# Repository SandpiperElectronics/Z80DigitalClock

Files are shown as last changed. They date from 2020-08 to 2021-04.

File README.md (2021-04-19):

# Z80 Digital Clock

## Description:
Built out of a Z80 microcomputer system of my own design, this clock can display Hours, Minutes, and Seconds and does so using an interupt from an Intel 82C53 Counter/Timer chip that is equally as vintage as the Z80.

## To Do: 
- [X] Clock Display
- [X] Clock Display PCB
- [X] Reset Circuit
- [X] Basic Functionality (ROM and CPU)
- [X] 8255 Peripheral Chip
- [X] 8253 Counter/Timer
- [ ] Write Display Sub Routine
- [ ] Clock Sub Routine
- [X] Buttons to Set time
- [ ] Sub routine for button input
- [ ] Z80 Clock PCB

## Images:

### Z80 Clock Schematic (New Version)
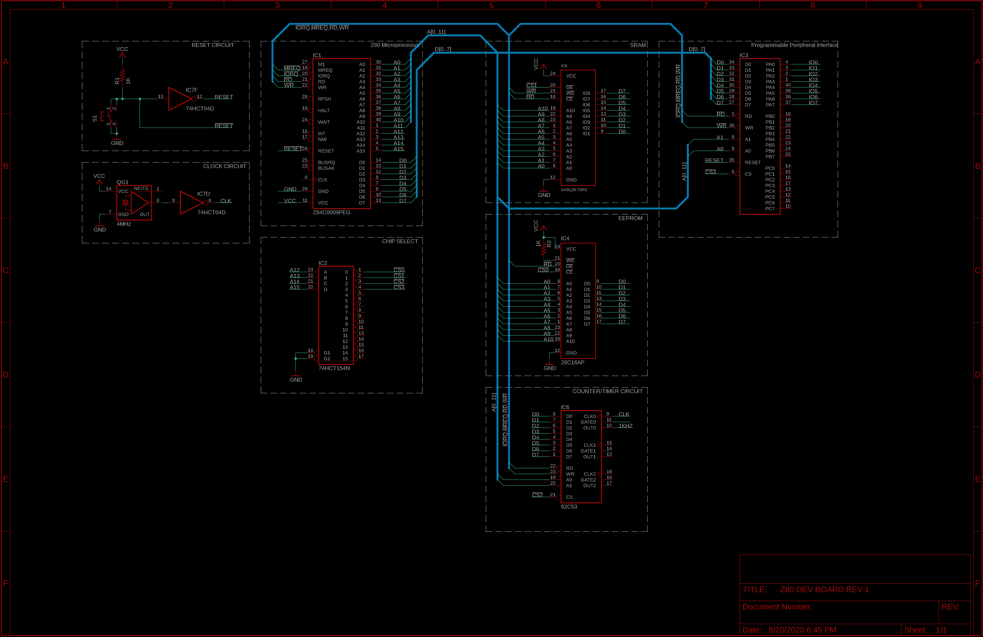
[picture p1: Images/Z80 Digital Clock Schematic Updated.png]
Image of Clock Schematic (NEW)


### Z80 Clock Schematic (Old Version)
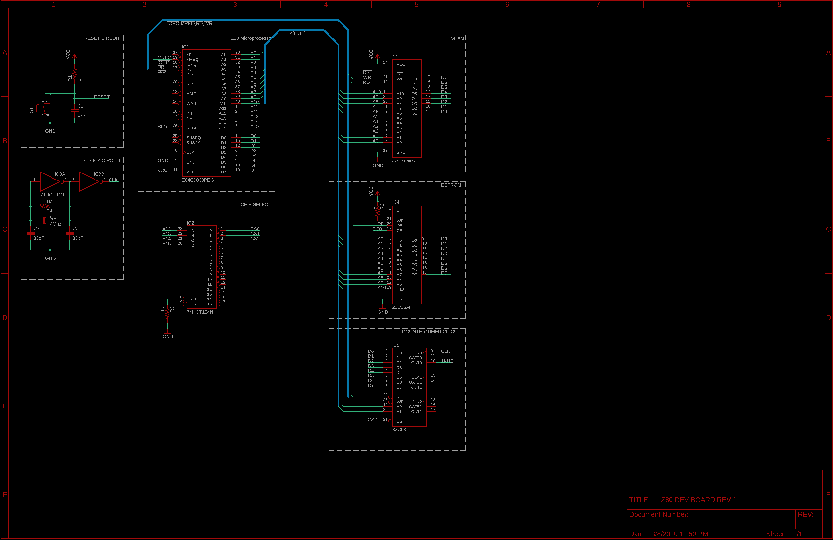
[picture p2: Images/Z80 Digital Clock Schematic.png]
Image of Clock Schematic (OLD)


### 7 Segment Peripheral Schematic
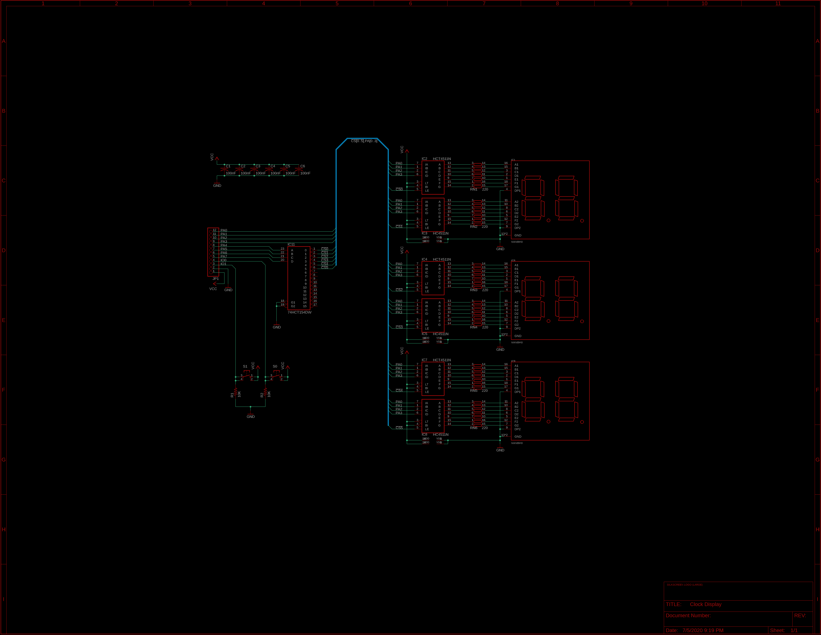
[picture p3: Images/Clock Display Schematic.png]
Image of 7 Segment Peripheral Schematic


### 7 Segment Peripheral Board Design
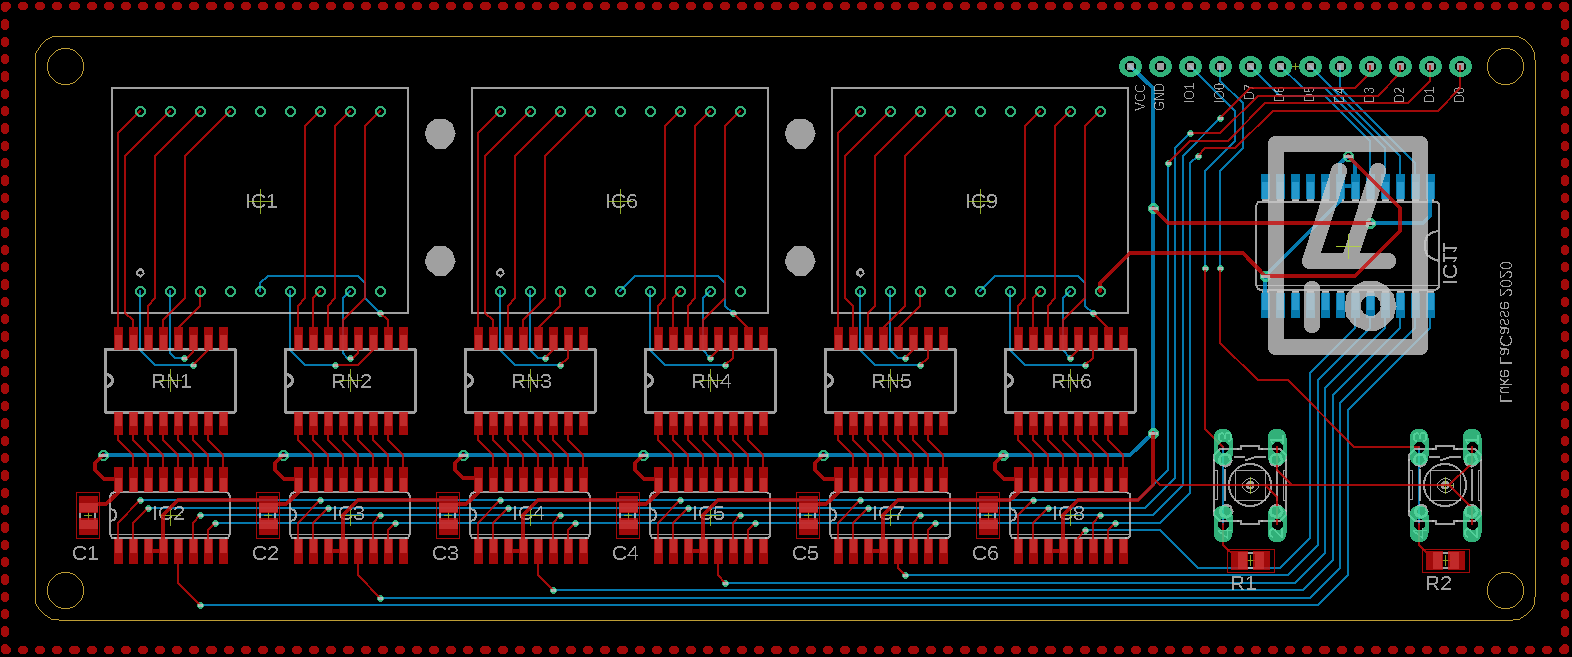
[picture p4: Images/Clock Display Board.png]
Image of 7 Sedment Peripheral PCB Design


### 7 Segment PCB and Z80 Clock
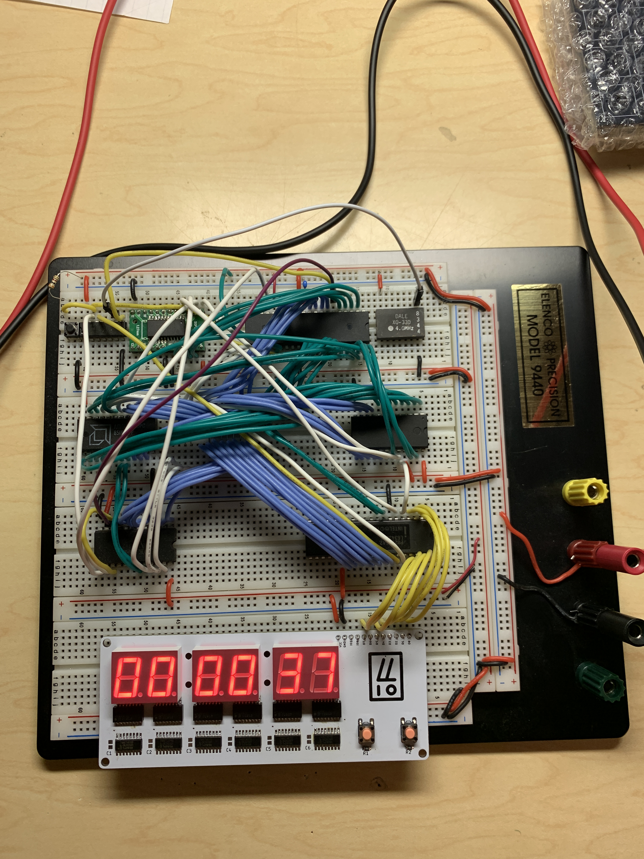
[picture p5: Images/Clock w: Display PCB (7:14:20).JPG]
Image of 7 Segment PCB and Z80 Clock


### 7 Segments in the Dark
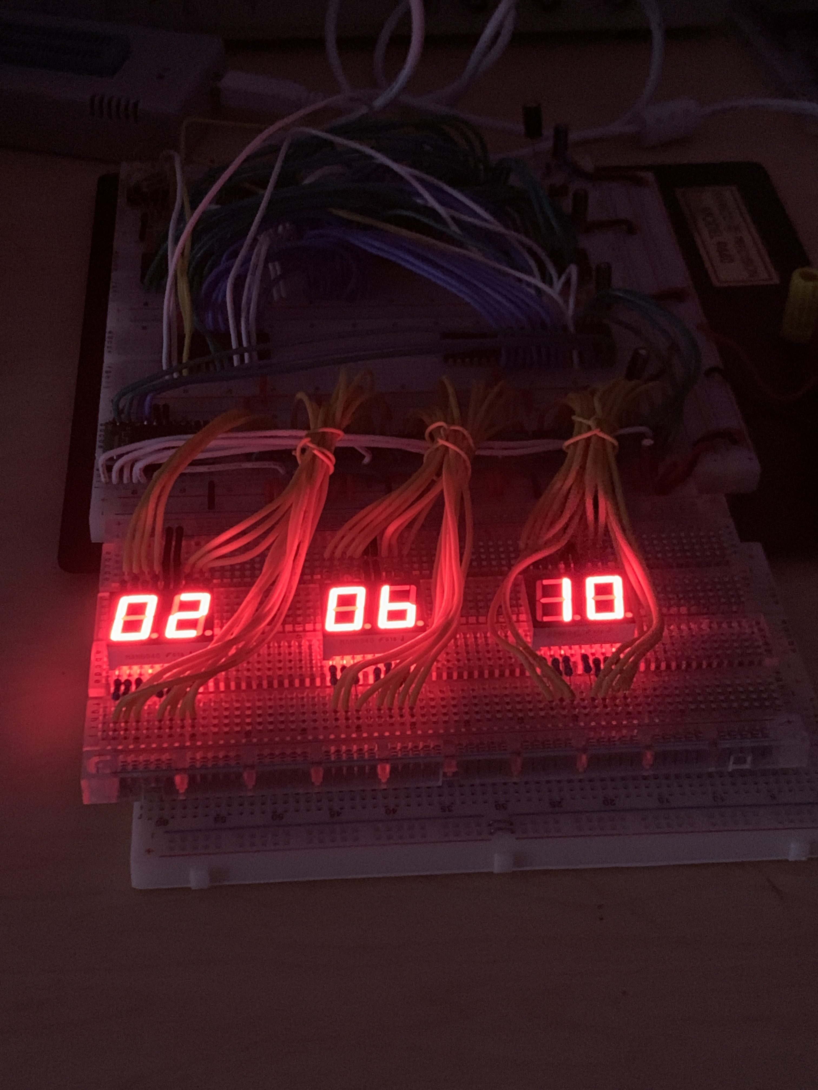
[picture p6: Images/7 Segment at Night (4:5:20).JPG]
Image of 7 Segments in the Dark


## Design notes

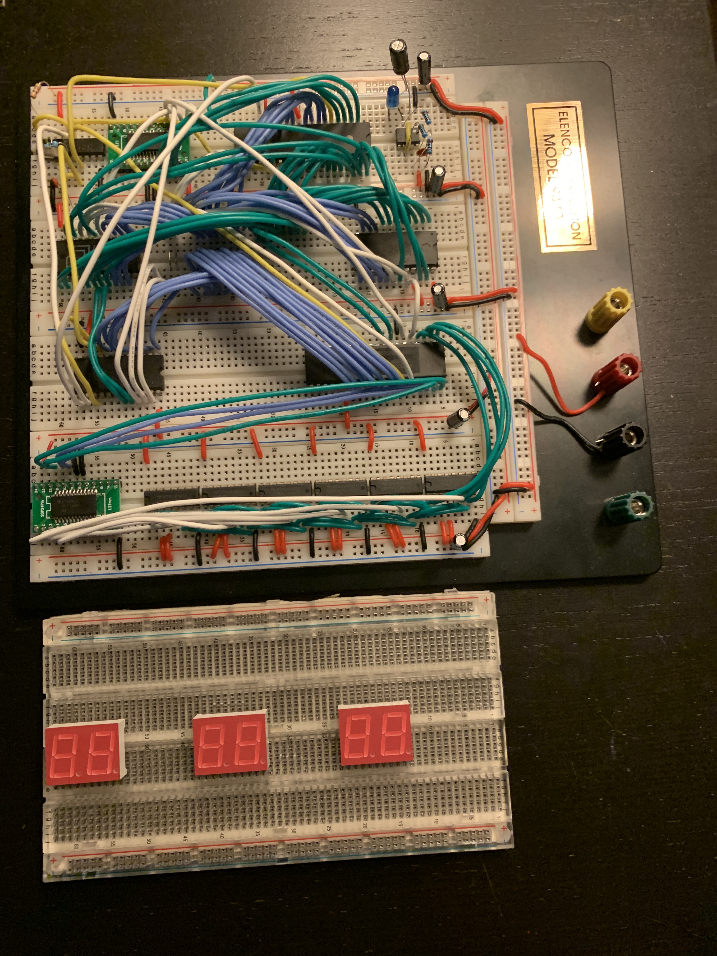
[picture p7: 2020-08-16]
Images/Before Connecting 7 Segment Displays (3:27:20) .JPG

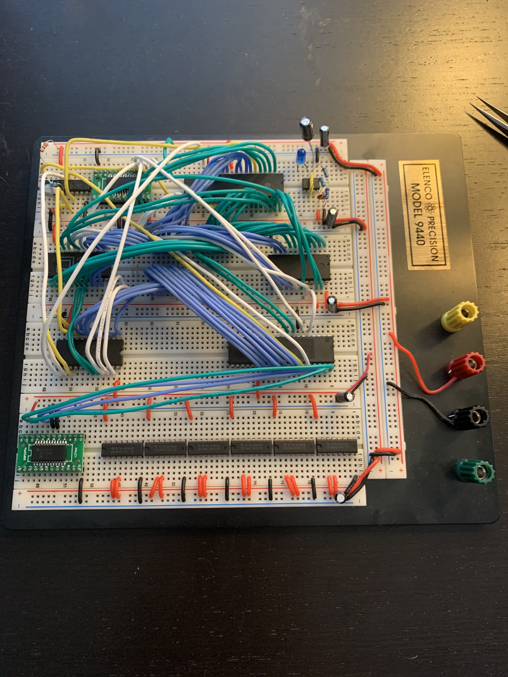
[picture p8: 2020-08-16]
Images/Adding 7 Segment Control (3:27:20).JPG

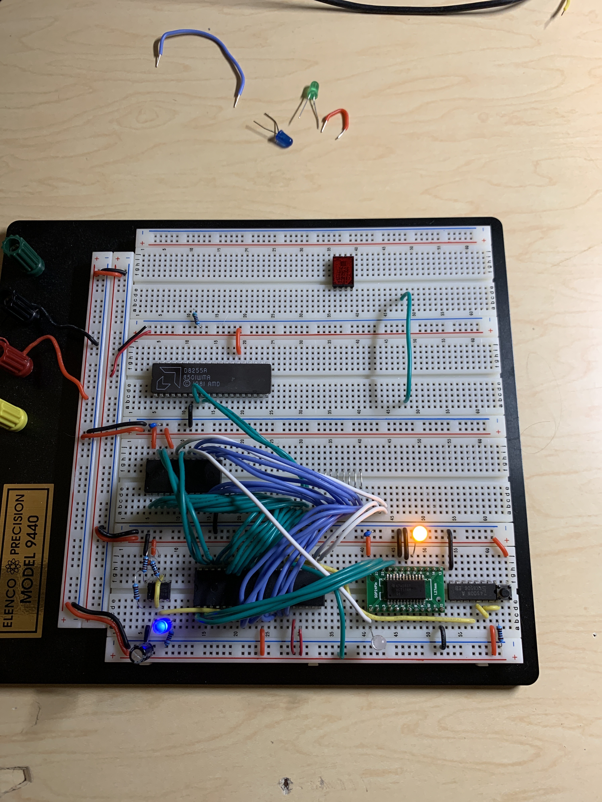
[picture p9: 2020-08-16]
Images/Early Stages (2:6:20).JPG

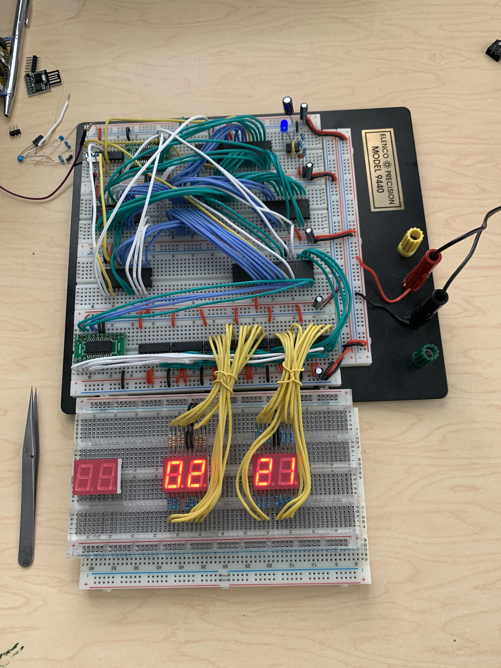
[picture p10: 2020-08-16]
Images/Two Displays Working (4:1:20).JPG

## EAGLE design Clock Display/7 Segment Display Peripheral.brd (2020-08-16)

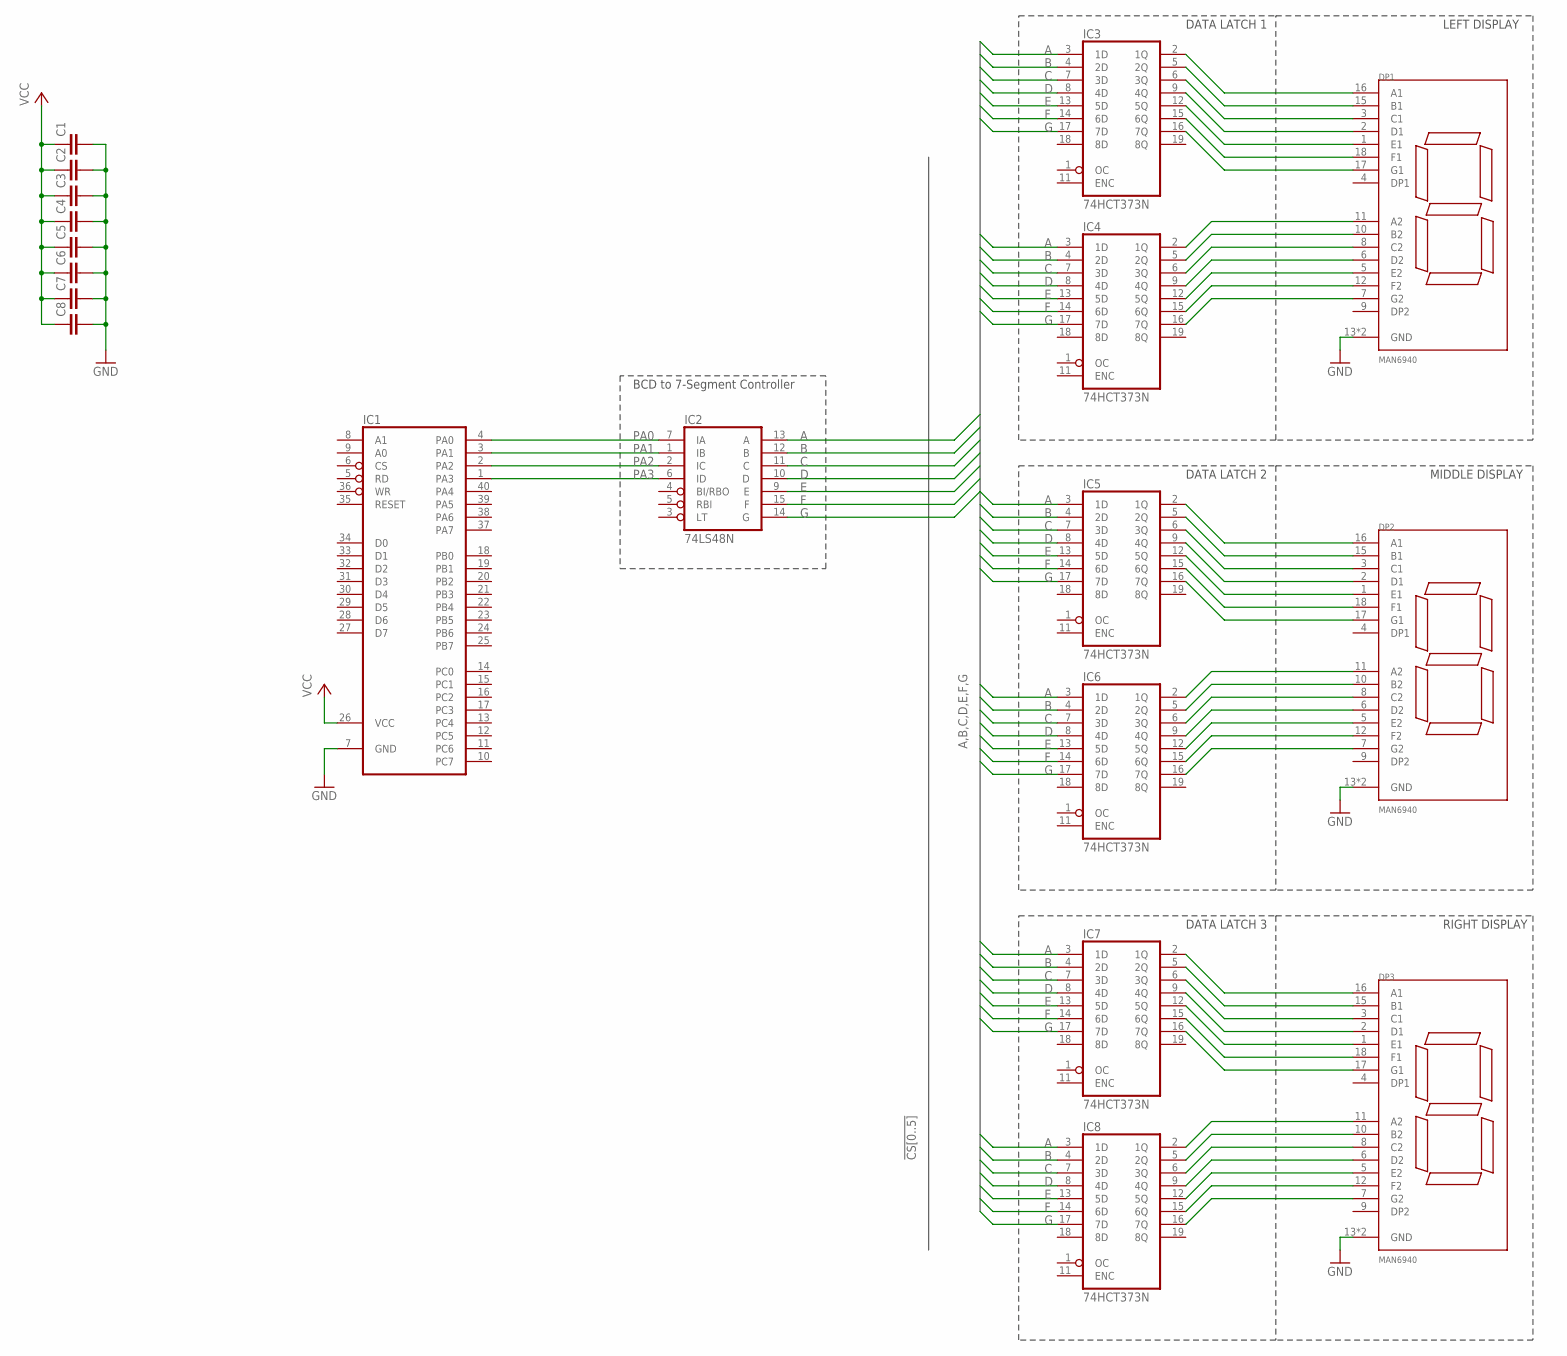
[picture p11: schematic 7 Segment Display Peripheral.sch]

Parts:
C1, C2, C3, C4, C5, C6, C7, C8: C-EU050-024X044; C050-024X044
DP1, DP2, DP3: MAN6940
IC1: 82C55A; DIL40
IC2: 74LS48N; DIL16
IC3, IC4, IC5, IC6, IC7, IC8: 74HCT373N; DIL20

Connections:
A: IC2.13 (A), IC3.3 (1D), IC4.3 (1D), IC5.3 (1D), IC6.3 (1D), IC7.3 (1D), IC8.3 (1D)
B: IC2.12 (B), IC3.4 (2D), IC4.4 (2D), IC5.4 (2D), IC6.4 (2D), IC7.4 (2D), IC8.4 (2D)
C: IC2.11 (C), IC3.7 (3D), IC4.7 (3D), IC5.7 (3D), IC6.7 (3D), IC7.7 (3D), IC8.7 (3D)
D: IC2.10 (D), IC3.8 (4D), IC4.8 (4D), IC5.8 (4D), IC6.8 (4D), IC7.8 (4D), IC8.8 (4D)
E: IC2.9 (E), IC3.13 (5D), IC4.13 (5D), IC5.13 (5D), IC6.13 (5D), IC7.13 (5D), IC8.13 (5D)
F: IC2.15 (F), IC3.14 (6D), IC4.14 (6D), IC5.14 (6D), IC6.14 (6D), IC7.14 (6D), IC8.14 (6D)
G: IC2.14 (G), IC3.17 (7D), IC4.17 (7D), IC5.17 (7D), IC6.17 (7D), IC7.17 (7D), IC8.17 (7D)
GND: C1.2, C2.2, C3.2, C4.2, C5.2, C6.2, C7.2, C8.2, DP1.13 (GND), DP1.14 (GND), DP2.13 (GND), DP2.14 (GND), DP3.13 (GND), DP3.14 (GND), IC1.7 (GND), IC2.8 (GND), IC3.10 (GND), IC4.10 (GND), IC5.10 (GND), IC6.10 (GND), IC7.10 (GND), IC8.10 (GND)
unnamed: DP1.17 (G1), IC3.16 (7Q)
unnamed: DP1.18 (F1), IC3.15 (6Q)
unnamed: DP1.1 (E1), IC3.12 (5Q)
unnamed: DP1.2 (D1), IC3.9 (4Q)
unnamed: DP1.3 (C1), IC3.6 (3Q)
unnamed: DP1.15 (B1), IC3.5 (2Q)
unnamed: DP1.16 (A1), IC3.2 (1Q)
unnamed: DP1.11 (A2), IC4.2 (1Q)
unnamed: DP1.10 (B2), IC4.5 (2Q)
unnamed: DP1.8 (C2), IC4.6 (3Q)
unnamed: DP1.6 (D2), IC4.9 (4Q)
unnamed: DP1.5 (E2), IC4.12 (5Q)
unnamed: DP1.12 (F2), IC4.15 (6Q)
unnamed: DP1.7 (G2), IC4.16 (7Q)
unnamed: DP2.17 (G1), IC5.16 (7Q)
unnamed: DP2.18 (F1), IC5.15 (6Q)
unnamed: DP2.1 (E1), IC5.12 (5Q)
unnamed: DP2.2 (D1), IC5.9 (4Q)
unnamed: DP2.3 (C1), IC5.6 (3Q)
unnamed: DP2.15 (B1), IC5.5 (2Q)
unnamed: DP2.16 (A1), IC5.2 (1Q)
unnamed: DP2.11 (A2), IC6.2 (1Q)
unnamed: DP2.10 (B2), IC6.5 (2Q)
unnamed: DP2.8 (C2), IC6.6 (3Q)
unnamed: DP2.6 (D2), IC6.9 (4Q)
unnamed: DP2.5 (E2), IC6.12 (5Q)
unnamed: DP2.12 (F2), IC6.15 (6Q)
unnamed: DP2.7 (G2), IC6.16 (7Q)
unnamed: DP3.17 (G1), IC7.16 (7Q)
unnamed: DP3.18 (F1), IC7.15 (6Q)
unnamed: DP3.1 (E1), IC7.12 (5Q)
unnamed: DP3.2 (D1), IC7.9 (4Q)
unnamed: DP3.3 (C1), IC7.6 (3Q)
unnamed: DP3.15 (B1), IC7.5 (2Q)
unnamed: DP3.16 (A1), IC7.2 (1Q)
unnamed: DP3.11 (A2), IC8.2 (1Q)
unnamed: DP3.10 (B2), IC8.5 (2Q)
unnamed: DP3.8 (C2), IC8.6 (3Q)
unnamed: DP3.6 (D2), IC8.9 (4Q)
unnamed: DP3.5 (E2), IC8.12 (5Q)
unnamed: DP3.12 (F2), IC8.15 (6Q)
unnamed: DP3.7 (G2), IC8.16 (7Q)
PA0: IC1.4 (PA0), IC2.7 (IA)
PA1: IC1.3 (PA1), IC2.1 (IB)
PA2: IC1.2 (PA2), IC2.2 (IC)
PA3: IC1.1 (PA3), IC2.6 (ID)
VCC: C1.1, C2.1, C3.1, C4.1, C5.1, C6.1, C7.1, C8.1, IC1.26 (VCC), IC2.16 (VCC), IC3.20 (VCC), IC4.20 (VCC), IC5.20 (VCC), IC6.20 (VCC), IC7.20 (VCC), IC8.20 (VCC)

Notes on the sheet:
LEFT DISPLAY
MIDDLE DISPLAY
RIGHT DISPLAY
BCD to 7-Segment Controller
DATA LATCH 1
DATA LATCH 2
DATA LATCH 3

Board: 2 copper layers, 19 parts (0 on the bottom side), 55 nets, no tracks yet.

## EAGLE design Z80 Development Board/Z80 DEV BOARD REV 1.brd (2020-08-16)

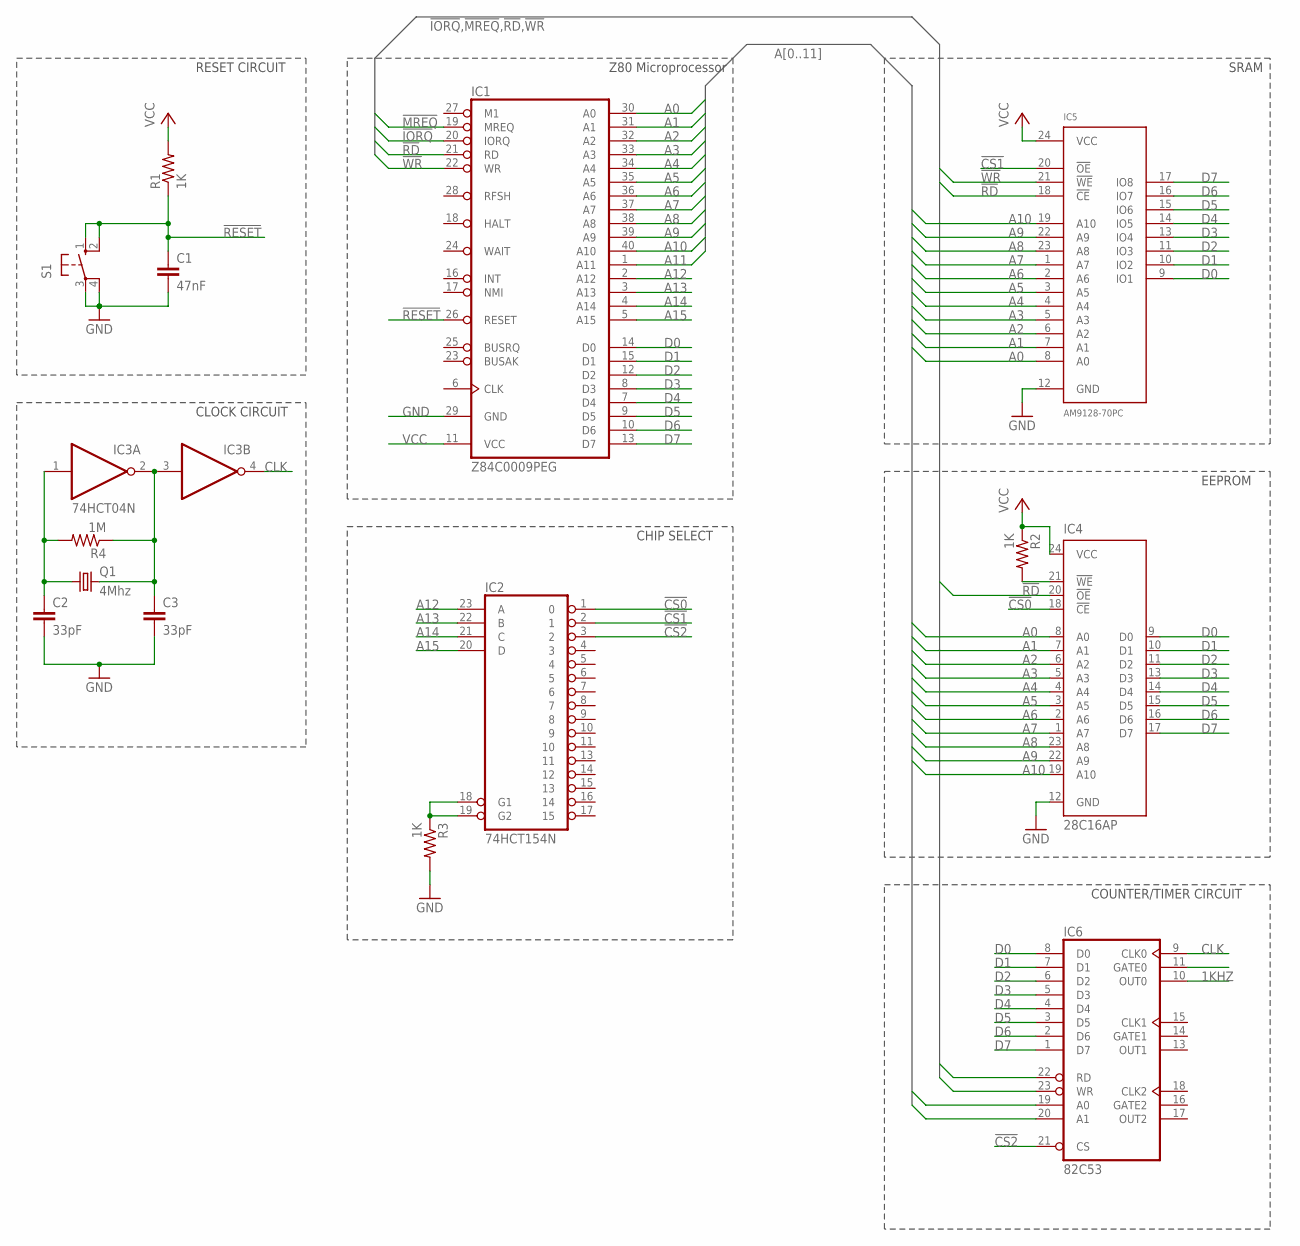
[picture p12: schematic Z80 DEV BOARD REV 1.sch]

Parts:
C1: 47nF; C050-035X075
C2, C3: 33pF; C050-035X075
IC1: Z84C0009PEG; DIL40
IC2: 74HCT154N; DIL24-6
IC3: 74HCT04N; DIL14
IC4: 28C16AP; DIL24-6
IC5: AM9128-70PC; DIL24-6
IC6: 82C53; DIL24-6
Q1: 4Mhz; HC49/S
R1, R2, R3: 1K; 0207/7
R4: 1M; 0207/7
S1: 10-XX; B3F-10XX

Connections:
1KHZ: IC6.10 (OUT0)
!CS0: IC2.1 (0), IC4.18 (!CE)
!CS1: IC2.2 (1), IC5.20 (!OE)
!CS2: IC2.3 (2), IC6.21 (CS)
!IORQ: IC1.20 (IORQ)
!MREQ: IC1.19 (MREQ)
!RD: IC1.21 (RD), IC4.20 (!OE), IC5.18 (!CE), IC6.22 (RD)
!RESET: C1.1, IC1.26 (RESET), R1.1, S1.1 (S), S1.2 (S1)
!WR: IC1.22 (WR), IC5.21 (!WE), IC6.23 (WR)
A0: IC1.30 (A0), IC4.8 (A0), IC5.8 (A0), IC6.19 (A0)
A1: IC1.31 (A1), IC4.7 (A1), IC5.7 (A1), IC6.20 (A1)
A2: IC1.32 (A2), IC4.6 (A2), IC5.6 (A2)
A3: IC1.33 (A3), IC4.5 (A3), IC5.5 (A3)
A4: IC1.34 (A4), IC4.4 (A4), IC5.4 (A4)
A5: IC1.35 (A5), IC4.3 (A5), IC5.3 (A5)
A6: IC1.36 (A6), IC4.2 (A6), IC5.2 (A6)
A7: IC1.37 (A7), IC4.1 (A7), IC5.1 (A7)
A8: IC1.38 (A8), IC4.23 (A8), IC5.23 (A8)
A9: IC1.39 (A9), IC4.22 (A9), IC5.22 (A9)
A10: IC1.40 (A10), IC4.19 (A10), IC5.19 (A10)
A11: IC1.1 (A11)
A12: IC1.2 (A12), IC2.23 (A)
A13: IC1.3 (A13), IC2.22 (B)
A14: IC1.4 (A14), IC2.21 (C)
A15: IC1.5 (A15), IC2.20 (D)
CLK: IC3.4 (O), IC6.9 (CLK0)
D0: IC1.14 (D0), IC4.9 (D0), IC5.9 (IO1), IC6.8 (D0)
D1: IC1.15 (D1), IC4.10 (D1), IC5.10 (IO2), IC6.7 (D1)
D2: IC1.12 (D2), IC4.11 (D2), IC5.11 (IO3), IC6.6 (D2)
D3: IC1.8 (D3), IC4.13 (D3), IC5.13 (IO4), IC6.5 (D3)
D4: IC1.7 (D4), IC4.14 (D4), IC5.14 (IO5), IC6.4 (D4)
D5: IC1.9 (D5), IC4.15 (D5), IC5.15 (IO6), IC6.3 (D5)
D6: IC1.10 (D6), IC4.16 (D6), IC5.16 (IO7), IC6.2 (D6)
D7: IC1.13 (D7), IC4.17 (D7), IC5.17 (IO8), IC6.1 (D7)
GND: C1.2, C2.2, C3.2, IC1.29 (GND), IC2.12 (GND), IC3.7 (GND), IC4.12 (GND), IC5.12 (GND), IC6.12 (GND), R3.2, S1.3, S1.4 (P1)
unnamed: C2.1, IC3.1 (I), Q1.1, R4.2
unnamed: IC4.21 (!WE), R2.2
unnamed: C3.1, IC3.2 (O), IC3.3 (I), Q1.2, R4.1
unnamed: IC2.18 (G1), IC2.19 (G2), R3.1
VCC: IC1.11 (VCC), IC2.24 (VCC), IC3.14 (VCC), IC4.24 (VCC), IC5.24 (VCC), IC6.24 (VCC), R1.2, R2.1

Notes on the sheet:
RESET CIRCUIT
Z80 Microprocessor
EEPROM
SRAM
CHIP SELECT
CLOCK CIRCUIT
COUNTER/TIMER CIRCUIT

Board: 2 copper layers, 15 parts (0 on the bottom side), 36 nets, no tracks yet.

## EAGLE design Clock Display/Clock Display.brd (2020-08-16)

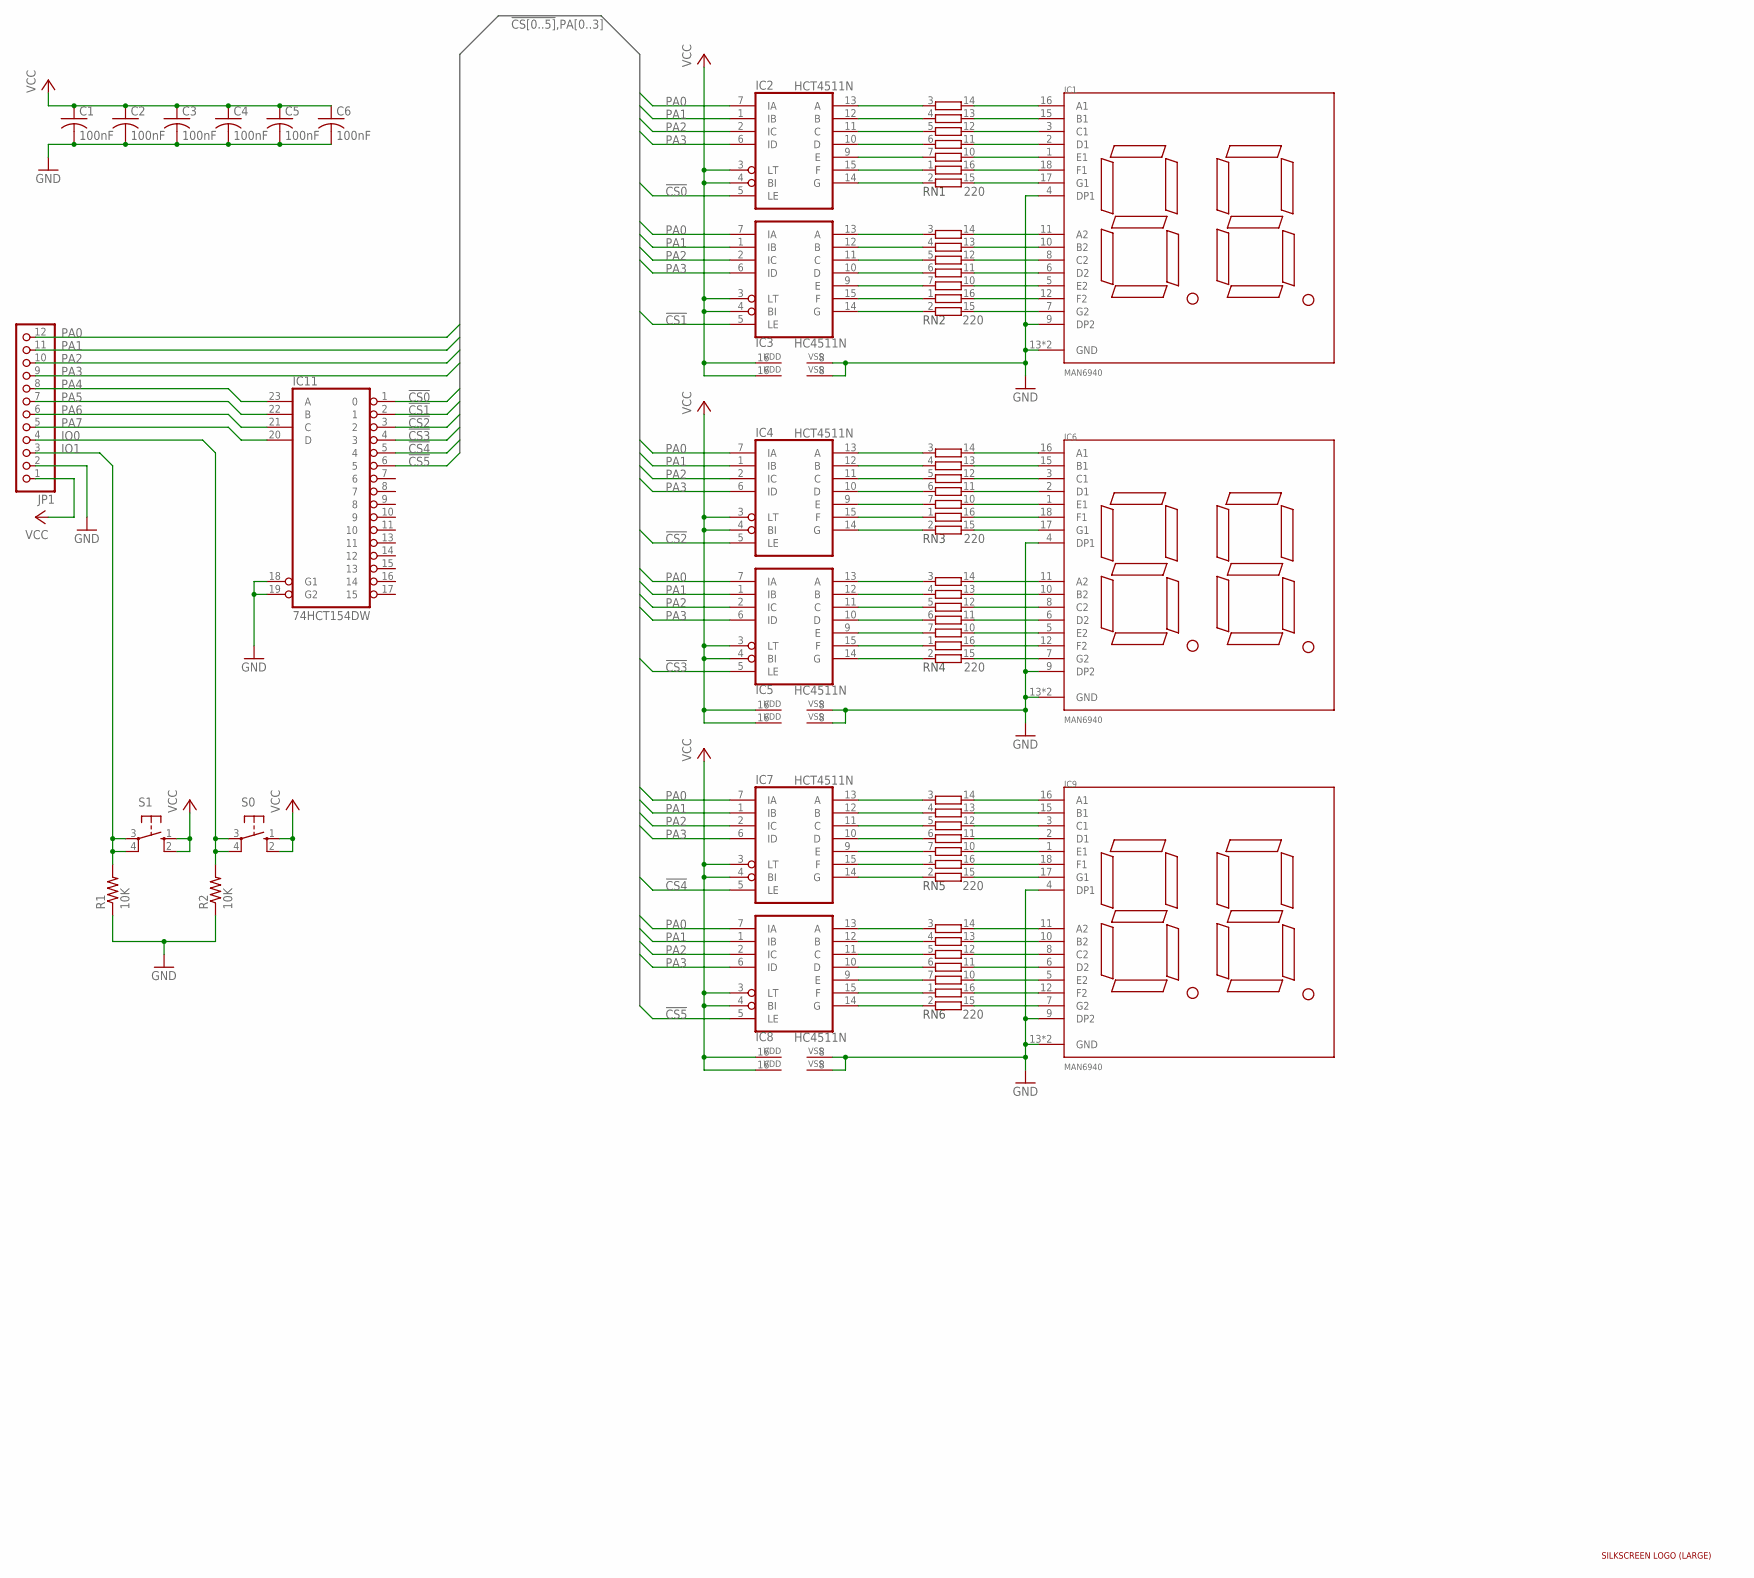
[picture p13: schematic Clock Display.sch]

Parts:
C1, C2, C3, C4, C5, C6: 100nF; C0805
IC1, IC6, IC9: MAN6940
IC2, IC4, IC7: HCT4511N; SO16
IC3, IC5, IC8: HC4511N; SO16
IC11: 74HCT154DW; SO24W
JP1: PINHD-1X12-CB; 1X12-CB
R1, R2: 10K; R0805
RN1, RN2, RN3, RN4, RN5, RN6: 220; SOMC16
S0, S1: 10-XX; B3F-10XX
U$1: LOGO_LARGE

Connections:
!CS0: IC2.5 (LE), IC11.1 (0)
!CS1: IC3.5 (LE), IC11.2 (1)
!CS2: IC4.5 (LE), IC11.3 (2)
!CS3: IC5.5 (LE), IC11.4 (3)
!CS4: IC7.5 (LE), IC11.5 (4)
!CS5: IC8.5 (LE), IC11.6 (5)
GND: C1.2, C2.2, C3.2, C4.2, C5.2, C6.2, IC1.4 (DP1), IC1.9 (DP2), IC1.13 (GND), IC1.14 (GND), IC2.8 (VSS), IC3.8 (VSS), IC4.8 (VSS), IC5.8 (VSS), IC6.4 (DP1), IC6.9 (DP2), IC6.13 (GND), IC6.14 (GND), IC7.8 (VSS), IC8.8 (VSS), IC9.4 (DP1), IC9.9 (DP2), IC9.13 (GND), IC9.14 (GND), IC11.12 (GND), IC11.18 (G1), IC11.19 (G2), JP1.2, R1.1, R2.1
IO0: JP1.4, R2.2, S0.3, S0.4 (P1)
IO1: JP1.3, R1.2, S1.3, S1.4 (P1)
unnamed: IC2.13 (A), RN1.3 (1)
unnamed: IC2.12 (B), RN1.4 (1)
unnamed: IC2.11 (C), RN1.5 (1)
unnamed: IC2.10 (D), RN1.6 (1)
unnamed: IC2.9 (E), RN1.7 (1)
unnamed: IC2.15 (F), RN1.1
unnamed: IC2.14 (G), RN1.2 (1)
unnamed: IC3.13 (A), RN2.3 (1)
unnamed: IC3.12 (B), RN2.4 (1)
unnamed: IC3.11 (C), RN2.5 (1)
unnamed: IC3.10 (D), RN2.6 (1)
unnamed: IC3.9 (E), RN2.7 (1)
unnamed: IC3.15 (F), RN2.1
unnamed: IC3.14 (G), RN2.2 (1)
unnamed: IC1.7 (G2), RN2.15 (2)
unnamed: IC1.12 (F2), RN2.16 (2)
unnamed: IC1.5 (E2), RN2.10 (2)
unnamed: IC1.6 (D2), RN2.11 (2)
unnamed: IC1.8 (C2), RN2.12 (2)
unnamed: IC1.10 (B2), RN2.13 (2)
unnamed: IC1.11 (A2), RN2.14 (2)
unnamed: IC1.17 (G1), RN1.15 (2)
unnamed: IC1.18 (F1), RN1.16 (2)
unnamed: IC1.1 (E1), RN1.10 (2)
unnamed: IC1.3 (C1), RN1.12 (2)
unnamed: IC1.2 (D1), RN1.11 (2)
unnamed: IC1.15 (B1), RN1.13 (2)
unnamed: IC1.16 (A1), RN1.14 (2)
unnamed: IC6.16 (A1), RN3.14 (2)
unnamed: IC6.15 (B1), RN3.13 (2)
unnamed: IC6.3 (C1), RN3.12 (2)
unnamed: IC6.2 (D1), RN3.11 (2)
unnamed: IC6.1 (E1), RN3.10 (2)
unnamed: IC6.18 (F1), RN3.16 (2)
unnamed: IC6.17 (G1), RN3.15 (2)
unnamed: IC6.11 (A2), RN4.14 (2)
unnamed: IC6.10 (B2), RN4.13 (2)
unnamed: IC6.8 (C2), RN4.12 (2)
unnamed: IC6.6 (D2), RN4.11 (2)
unnamed: IC6.5 (E2), RN4.10 (2)
unnamed: IC6.12 (F2), RN4.16 (2)
unnamed: IC6.7 (G2), RN4.15 (2)
unnamed: IC4.13 (A), RN3.3 (1)
unnamed: IC4.12 (B), RN3.4 (1)
unnamed: IC4.11 (C), RN3.5 (1)
unnamed: IC4.10 (D), RN3.6 (1)
unnamed: IC4.9 (E), RN3.7 (1)
unnamed: IC4.15 (F), RN3.1
unnamed: IC4.14 (G), RN3.2 (1)
unnamed: IC5.13 (A), RN4.3 (1)
unnamed: IC5.12 (B), RN4.4 (1)
unnamed: IC5.11 (C), RN4.5 (1)
unnamed: IC5.10 (D), RN4.6 (1)
unnamed: IC5.9 (E), RN4.7 (1)
unnamed: IC5.15 (F), RN4.1
unnamed: IC5.14 (G), RN4.2 (1)
unnamed: IC9.16 (A1), RN5.14 (2)
unnamed: IC9.15 (B1), RN5.13 (2)
unnamed: IC9.3 (C1), RN5.12 (2)
unnamed: IC9.2 (D1), RN5.11 (2)
unnamed: IC9.1 (E1), RN5.10 (2)
unnamed: IC9.18 (F1), RN5.16 (2)
unnamed: IC9.17 (G1), RN5.15 (2)
unnamed: IC9.11 (A2), RN6.14 (2)
unnamed: IC9.10 (B2), RN6.13 (2)
unnamed: IC9.8 (C2), RN6.12 (2)
unnamed: IC9.6 (D2), RN6.11 (2)
unnamed: IC9.5 (E2), RN6.10 (2)
unnamed: IC9.12 (F2), RN6.16 (2)
unnamed: IC9.7 (G2), RN6.15 (2)
unnamed: IC7.13 (A), RN5.3 (1)
unnamed: IC7.12 (B), RN5.4 (1)
unnamed: IC7.11 (C), RN5.5 (1)
unnamed: IC7.10 (D), RN5.6 (1)
unnamed: IC7.9 (E), RN5.7 (1)
unnamed: IC7.15 (F), RN5.1
unnamed: IC7.14 (G), RN5.2 (1)
unnamed: IC8.13 (A), RN6.3 (1)
unnamed: IC8.12 (B), RN6.4 (1)
unnamed: IC8.11 (C), RN6.5 (1)
unnamed: IC8.10 (D), RN6.6 (1)
unnamed: IC8.9 (E), RN6.7 (1)
unnamed: IC8.15 (F), RN6.1
unnamed: IC8.14 (G), RN6.2 (1)
PA0: IC2.7 (IA), IC3.7 (IA), IC4.7 (IA), IC5.7 (IA), IC7.7 (IA), IC8.7 (IA), JP1.12
PA1: IC2.1 (IB), IC3.1 (IB), IC4.1 (IB), IC5.1 (IB), IC7.1 (IB), IC8.1 (IB), JP1.11
PA2: IC2.2 (IC), IC3.2 (IC), IC4.2 (IC), IC5.2 (IC), IC7.2 (IC), IC8.2 (IC), JP1.10
PA3: IC2.6 (ID), IC3.6 (ID), IC4.6 (ID), IC5.6 (ID), IC7.6 (ID), IC8.6 (ID), JP1.9
PA4: IC11.23 (A), JP1.8
PA5: IC11.22 (B), JP1.7
PA6: IC11.21 (C), JP1.6
PA7: IC11.20 (D), JP1.5
VCC: C1.1, C2.1, C3.1, C4.1, C5.1, C6.1, IC2.3 (LT), IC2.4 (BI), IC2.16 (VDD), IC3.3 (LT), IC3.4 (BI), IC3.16 (VDD), IC4.3 (LT), IC4.4 (BI), IC4.16 (VDD), IC5.3 (LT), IC5.4 (BI), IC5.16 (VDD), IC7.3 (LT), IC7.4 (BI), IC7.16 (VDD), IC8.3 (LT), IC8.4 (BI), IC8.16 (VDD), IC11.24 (VCC), JP1.1, S0.1 (S), S0.2 (S1), S1.1 (S), S1.2 (S1)

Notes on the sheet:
RN1
RN2
RN3
RN4
RN5
RN6

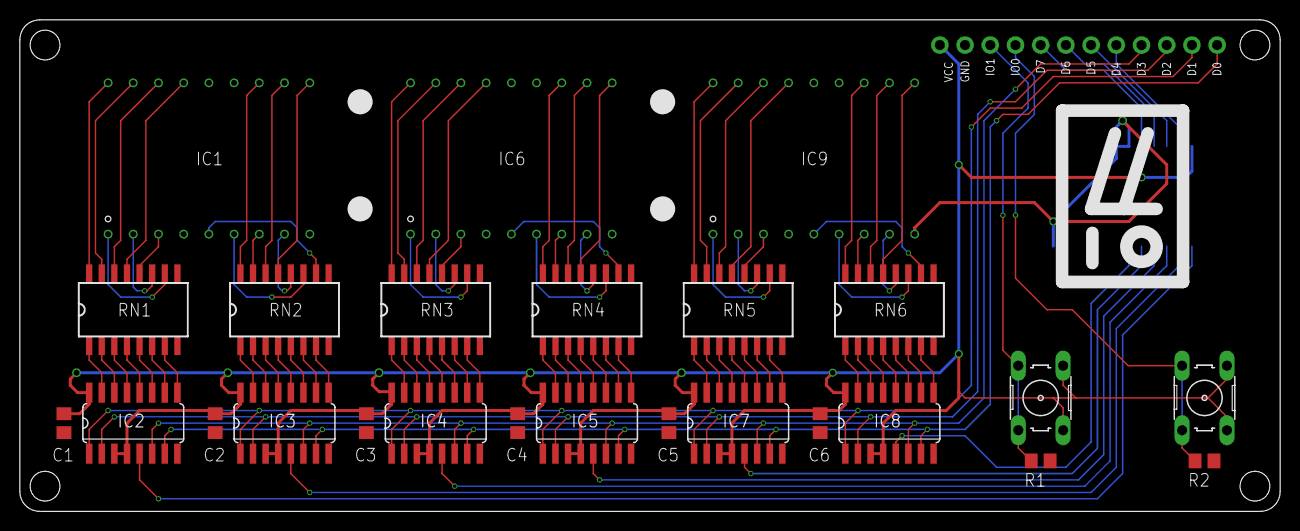
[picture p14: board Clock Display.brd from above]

Board: 2 copper layers, 127.0 x 49.5 mm, 28 parts (1 on the bottom side), 102 nets.

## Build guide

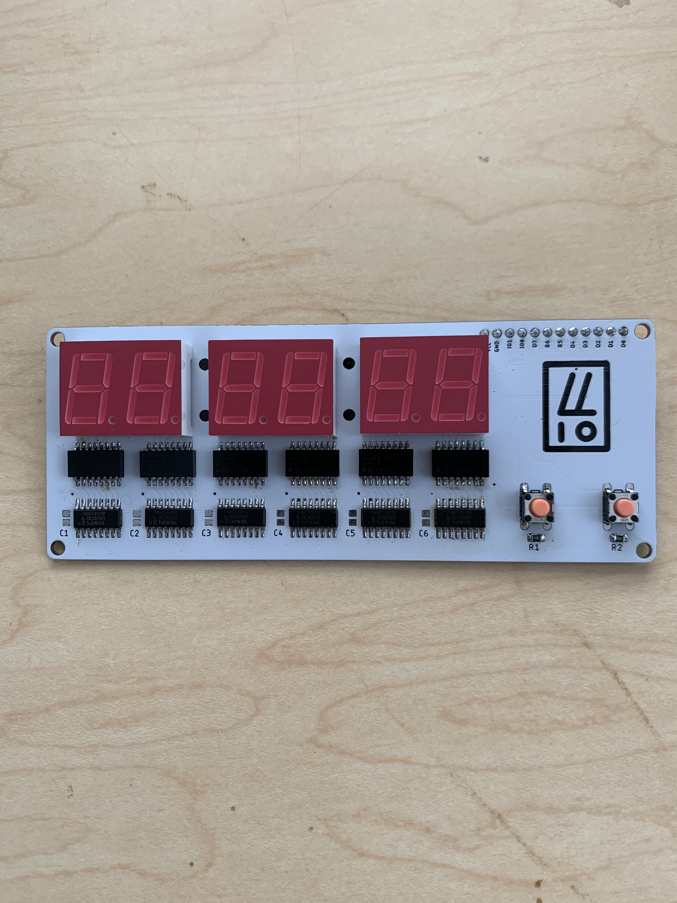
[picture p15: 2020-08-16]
Images/Display PCB Assembled (7:14:20).JPG

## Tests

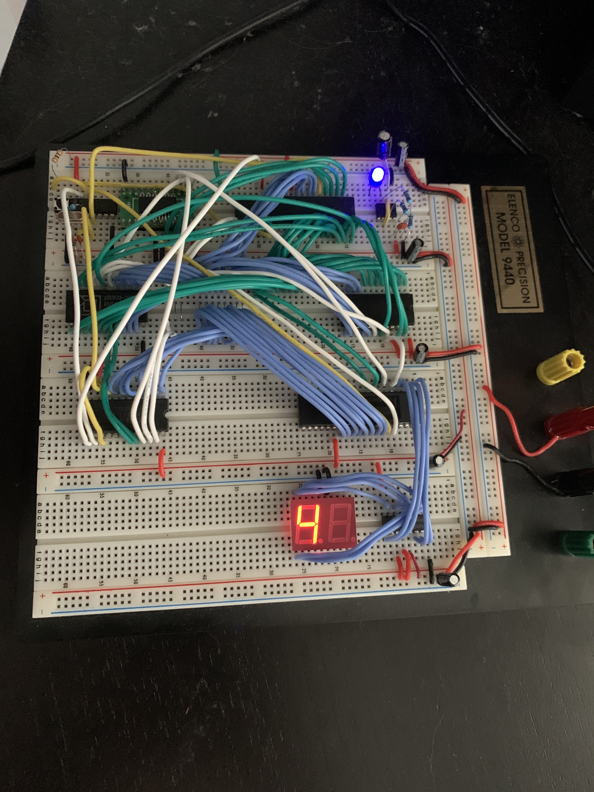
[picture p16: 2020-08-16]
Images/7 Segment Test w: PIO (3:25:20).JPG

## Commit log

2020-08-16 Early Version of the 7-Segment Display Peripheral
    This was an early prototype of the 7-Segment Display Peripheral used to construct the breadboard version of the circuit. I switched to surface mount components for the final version of this periphera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
    [7 Segment Display Peripheral.brd, 7 Segment Display Peripheral.sch]
2020-08-16 Rename 7 Segment Display Peripheral.brd to Clock Display/7 Segment Display Peripheral.brd
    [7 Segment Display Peripheral.brd]
2020-08-16 Rename 7 Segment Display Peripheral.sch to Clock Display/7 Segment Display Peripheral.sch
    [7 Segment Display Peripheral.sch]
2022-02-27 Uploaded Z80 Clock Code V2
    Improvements on readability.
    Implement a count by millisecond instead of seconds for increased accuracy in addition to only using a single counter output.
